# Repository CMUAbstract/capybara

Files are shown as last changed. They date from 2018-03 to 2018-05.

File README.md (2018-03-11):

# HW Design Files for Capybara board

Capybara is an energy-harvesting sensor node that runs on solar panels or RF
energy (from 915MHz RFID transmitters), and features a power system with
reconfigurable energy storage for provisioning energy bursts on demand
([details and link to
paper](https://github.com/CMUAbstract/releases/blob/master/Capybara.md)). The board
includes the following sensors:

* IMU: LSM6DS3
* Magnetometer: HMC5883L
* Proximity/Gesture/Light/Color: APDS-9960
* Barometer: LPS22HB
* Phototransistor
* Analog MEMS microphone

[Schematic PDF](Project%20Outputs%20for%20Capybara/CapybaraSchematic.PDF)

[Gerber and Drill files](Project%20Outputs%20for%20Capybara/capybara-v2-gerber)

[BOM](Project%20Outputs%20for%20Capybara/BOM-v2-0.xls)

Please contact us if you are interested in blank or assembled PCB boards.

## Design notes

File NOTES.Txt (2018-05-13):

No BQ bypass configuration:
Can use internal supervisor inside BQ (VBAT_OK) for BOOST_EN signal
populate R73
unpopulate R60

optionally for VBANK_OK signal for the MCU populate either:
   to use the supervisor as the source of the signal: populate R63 and R62,  unpopulate R61
   to use the VBAT_OK as the source of the signal: populate R61, unpopulate R63, R62.

With BQ bypass, CANNOT use the internal (VBAT_OK) for BOOST_EN signal,
because during the bypass BQ output is disconnected from the main cap,
so it will reach top voltage, and VBAT_OK will go high, BEFORE the
main cap bank charges.

Tested cap config:
Output of output booster (C51,C52,C53): none
Input of output booster (C44,C45): 100uF     (ceramic)
Bank0-internal (C30,C31,C29): 200uF=2x 100uF (ceramic)
Bank0 (C1,C2): none

Tested config:
Use U9 (BU49) supervisor for ON trigger: works  (config chosen, i.e. last tested)
Use VBAT_OK interal supervisor in BQ for ON trigger: works

Issue: zigzag in VDD -- possibly due to the failed-start problem (tune C54,R86 on gate of shutdown FET Q26).

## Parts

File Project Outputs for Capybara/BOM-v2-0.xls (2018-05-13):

Distributor | Comment | Description | Designator | Distributor Part Number | LibRef | Manufacture Part Number | Manufacturer | Manufacturer Part Number | Quantity | Value | Layer
Mouser | Cap - Polarized | Polarized Capacitor | C1, C2, C3, C4, C5, C6, C7, C8, C9, C10, C11, C12, C13, C14 | 628-CPX3225A752D | Cap - Polarized |  | Seiko Instruments | CPX3225A752D | 14 | 7.5mF | Bottom
Mouser | 304DCN2R7SCBB | EDLC Supercap | C15, C16, C17, C18, C19 | 598-304DCN2R7SCBB | SUPERCAP |  | Illinois Capacitor / CDE | 304DCN2R7SCBB | 5 | 300mF | Bottom
Mouser | SUPERCAP_DUAL_SERIES | EDLC Supercap Dual with Balancing Terminal | C20 | 81-DMT3N4R2U224M3DT0 | SUPERCAP_DUAL_SERIES |  | Murata Electronics | DMT3N4R2U224M3DTA0 | 1 | 220mF | Bottom
Mouser | SUPERCAP_DUAL | EDLC Supercap Dual | C21 | 81-DMHA14R5V353M4ATA | SUPERCAP_DUAL |  | Murata Electronics | DMHA14R5V353M4ATA0 | 1 | 35mF | Bottom
Digi-Key | Cap | Ceramic Capacitor (Surface Mount) | C22, C23, C24, C25, C59, C60, C82, C107 | 490-1543-1-ND | Cap |  | Murata Electronics North America | GRM188R61A105KA61D | 8 | 1uF | Bottom, Bottom, Bottom, Bottom, Top, Top, Top, Top
Digi-Key | Cap | Ceramic Capacitor (Surface Mount) | C26, C33, C35, C39, C43, C49, C50, C62, C64, C67, C68, C74, C75, C76, C77, C78, C102, C112, C113, C115, C117 | 490-1532-1-ND | Cap |  | Murata Electronics North America | GRM188R71C104KA01D | 21 | 0.1uF | Bottom, Bottom, Bottom, Bottom, Bottom, Bottom, Bottom, Top, Top, Top, Top, Top, Top, Top, Top, Top, Top, Bottom, Top, Bottom, Bottom
Digi-Key | Cap | Ceramic Capacitor (Surface Mount) | C27, C28, C32, C37, C42, C55, C56, C57, C58, C71, C72, C104, C118, C120, C121 | 490-3296-1-ND | Cap |  | Murata Electronics North America | GRM188R61C225KE15D | 15 | 2.2uF | Bottom, Bottom, Bottom, Bottom, Bottom, Top, Top, Top, Top, Top, Top, Top, Bottom, Bottom, Bottom
Digi-Key | Cap | Ceramic Capacitor (Surface Mount) | C29 | 490-13981-1-ND | Cap |  | Murata Electronics North America | GRM21BR60J107ME15L | 1 | 100uF | Bottom
Digi-Key | Cap | Ceramic Capacitor (Surface Mount) | C30, C31, C40, C44, C45, C51, C52, C53 | 490-10510-1-ND | Cap |  | Murata Electronics North America | GRM21BR60G107ME15L | 8 | 100uF | Bottom
Digi-Key | Cap | Ceramic Capacitor (Surface Mount), Ceramic Capacitor (Surface Mount), CAP CER 4.7UF 4V X6S, Ceramic Capacitor (Surface Mount) | C34, C63, C65, C103 | 1276-2087-1-ND | Cap |  | Samsung Electro-Mechanics | CL10B475KQ8NQNC | 4 | 4.7uF | Bottom, Top, Top, Top
Digi-Key | Cap | Ceramic Capacitor (Surface Mount) | C36, C66, C119 | 490-3290-1-ND | Cap |  | Murata Electronics North America | GRM188R71E224KA88D | 3 | 0.22uF | Bottom, Top, Bottom
Digi-Key | Cap | Ceramic Capacitor (Surface Mount) | C38 | 1276-6528-1-ND | Cap |  | Samsung Electro-Mechanics | CL10A476MR8NZNE | 1 | 47uF | Bottom
Mouser | Cap | Ceramic Capacitor (Surface Mount) | C41 | 80-C0603C103J5R | Cap |  | KEMET | C0603C103J5RACTU | 1 | 0.01uF | Bottom
Digi-Key | Cap | Ceramic Capacitor (Surface Mount) | C46, C73, C79 | 490-3896-1-ND | Cap |  | Murata Electronics North America | GRM188R60J106ME47D | 3 | 10uF | Bottom, Top, Top
Digi-Key | Cap | Ceramic Capacitor (Surface Mount) | C47 | 490-10748-1-ND | Cap |  | Murata Electronics North America | GRM21BR61E106MA73L | 1 | 10uF | Bottom
 | Cap | Ceramic Capacitor (Surface Mount) | C48 |  | Cap |  | Generic Ceramic Chip Cap (TBD) |  | 1 | TBD | Bottom
Digi-Key | Cap | Ceramic Capacitor (Surface Mount) | C54 | 1276-1984-1-ND | Cap |  | Samsung Electro-Mechanics | CL10B203KB8NNNC | 1 | 0.02uF | Bottom
Digi-Key | Cap - Polarized | Polarized Capacitor | C61 | 490-10510-1-ND | Cap - Polarized |  | Murata Electronics North America | GRM21BR60G107ME15L | 1 | 100uF | Top
Digi-Key | Cap | Ceramic Capacitor (Surface Mount) | C69, C70, C101, C105 | 399-1061-1-ND | Cap |  | Kemet | C0603C101J5GACTU | 4 | 100pF | Top
Mouser | Cap | Ceramic Capacitor (Surface Mount) | C80, C81 | 581-04025A100MAT2A | Cap |  | AvX | 04025A100MAT2A | 2 | 10pF | Top
Digi-Key | Cap | Ceramic Capacitor (Surface Mount) | C83, C84 | 490-8222-1-ND | Cap |  | Murata Electronics North America | GRM1555C1H6R0CA01D | 2 | 6pF | Top
Digi-Key | Cap | Ceramic Capacitor (Surface Mount) | C85, C114 | 490-1459-1-ND | Cap |  | Murata Electronics North America | GRM1885C1H222JA01D | 2 | 2.2nF | Top
Digi-Key | Cap | Ceramic Capacitor (Surface Mount) | C86, C87, C90, C92, C99 | 490-6073-1-ND | Cap |  | Murata Electronics | GJM1555C1H1R0BB01D | 5 | 1pF | Top
 | Cap | Ceramic Capacitor (Surface Mount) | C88, C89 |  | Cap |  | Generic Ceramic Chip Cap (TBD) |  | 2 |  | Top
Digikey | Cap | Ceramic Capacitor (Surface Mount) | C91 | 490-6263-1-nd | Cap |  | Murata Electronics |  | 1 | 0.5pF | Top
Mouser | Cap | Ceramic Capacitor (Surface Mount) | C93, C94, C97 | 609-500R07S330JV4T | Cap |  | Johanson | 500R07S330JV4T | 3 | 33pF | Top
Mouser | Cap | Ceramic Capacitor (Surface Mount) | C95 | 609-500R07S5R6CV4T | Cap |  | Johanson | 500R07S5R6CV4T | 1 | 2.2pF | Top
Digi-Key | Cap | Ceramic Capacitor (Surface Mount) | C96 | 490-1312-1-ND | Cap |  | Murata Electronics North America | GRM155R71E103KA01D | 1 | 10000pF | Top
Mouser | Cap | Ceramic Capacitor (Surface Mount) | C98 | 609-500R07S100JV4T | Cap |  | Johanson | 500R07S100JV4T | 1 | 10pF | Top
Mouser | Cap | Ceramic Capacitor (Surface Mount) | C100 | 81-GRM1555C1H102JA1D | Cap |  | Generic Ceramic Chip Cap (TBD) | GRM1555C1H102JA01D | 1 | 1000pF | Top
Digi-Key | Cap | Ceramic Capacitor (Surface Mount) | C106 | 445-5192-1-ND | Cap |  | TDK Corporation | C1608X7R1C474K080AC | 1 | 0.47uF | Top
Digi-Key | Cap | Ceramic Capacitor (Surface Mount) | C108, C109 | 490-5867-1-ND | Cap |  | Murata Electronics North America | GRM1555C1H8R0DA01D | 2 | 8pF | Top
Digi-Key | Cap | Ceramic Capacitor (Surface Mount) | C110, C111 | 490-5873-1-ND | Cap |  | Murata Electronics North America | GRM1555C1H4R0CA01D | 2 | 4pF | Top
Digi-Key | Cap | Ceramic Capacitor (Surface Mount) | C116 | 490-3287-1-ND | Cap |  | Murata Electronics North America | GRM188R71H473KA61D | 1 | 0.047uF | Bottom
Mouser | COAX_SMALL | ms-156hf | CO1 | 798-MS156HF20 | COAX_SMALL |  | Hirose Connector | MS-156HF(20) | 1 |  | Top
Mouser | Diode | General Purpose Diode | D1, D2, D3, D4, D5, D6, D7, D8, D9, D10, D11, D12, D13, D14, D15, D16, D17, D18, D19, D20, D21, D22, D23, D24, D25, D26, D27, D29, D30, D31, D32, D33, D34, D35, D36, D39, D40 | 78-BAS40-02V-V-G-08 | Diode |  | Vishay Semiconductor | BAS40-02V-V-G-08 | 37 |  | Bottom, Bottom, Bottom, Bottom, Bottom, Bottom, Bottom, Bottom, Bottom, Bottom, Bottom, Bottom, Bottom, Bottom, Bottom, Bottom, Bottom, Bottom, Bottom, Bottom, Bottom, Bottom, Bottom, Bottom, Bottom, Bottom, Bottom, Bottom, Bottom, Bottom, Bottom, Bottom, Bottom, Bottom, Top, Bottom, Bottom
Digikey | 3.0V | 1.0 A Surface Mount Schottky Barrier Rectifier, 40 V, -65 to 125 degC, 2-Pin SOD-123 Package, RoHS, Tape and Reel | D28 | MMSZ4683-TPMSCT-ND | CMP-0303-00003-1 |  | Micro Commercial Co | MMSZ4683-TP | 1 |  | Bottom
Mouser | HSMS-285C | Agilent Schottky Diode, Two in Series, Small Package SOT-323 | D37, D38 | 630-HSMS-285C-BLKG | HSMS-285C |  | Avago Technologies US Inc. | HSMS-285C-BLKG | 2 |  | Top
 | FIDUCIAL |  | F1, F2, F3 |  | FIDUCIAL |  |  |  | 3 |  | Top
Digikey | Ferrite Bead | Ferrite bead, RF choke | FB1, FB2 | 490-5216-1-ND | Ferrite Bead |  | Murata Electronics North America | BLM18HE152SN1D | 2 |  | Top
Digikey | JTAG | Header, 50mil, 5x2, Gold, TH | J1 | SAM8798-ND | GRPB052VWVN-RC |  | Samtec Inc. | FTSH-105-01-L-D-K | 1 |  | Top
Mouser | MMCX | MMCX RF Connector | J2 | 538-73415-1001 | MMCX |  | Molex | 0734151001 | 1 |  | Top
 | JUMPER |  | JU1, JU2 |  | JUMPER |  |  |  | 2 |  | Bottom
Mouser | Ind | Inductor | L1, L2 | 994-PFL1609-472MEU | Inductor |  | Coilcraft | PFL1609-472MEU | 2 | 4.7uH | Bottom
Mouser | Ind | Inductor (Surface Mount) | L3 | 963-LB1608T100M | Ind |  | Taiyo Yuden | LB1608T100M | 1 | 10uH | Top
Digikey | Ind | Inductor (Surface Mount) | L4 | 490-8389-1-ND | Ind |  | Murata Electronics North America | LQG15HS2N4S02D | 1 | 2.4nH | Top
Digikey | Ind | Inductor (Surface Mount) | L5, L6 | 490-6569-1-ND | Ind |  | Murata Electronics North America | LQG15HS2N0S02D | 2 | 2nH | Top
Digikey | Ind | Inductor (Surface Mount) | L7 | 490-8389-1-ND | Ind |  | Murata Electronics North America | Murata Electronics North America | 1 | 2.4nH | Top
Mouser | Ind | Inductor (Surface Mount) | L8 | 994-0402CS-22NXGLU | Ind |  | Coilcraft (http://www.coilcraft.com/0402cs.cfm) | 0402CS-22NX_LU | 1 | 22nH | Top
Digikey | JMPHDR_12 |  | P1 | S9015E-12-ND | JMPHDR_12 |  | Sullins Connector Solutions | GRPB122VWVN-RC | 1 |  | Top
Digikey | JMPHDR_8 |  | P2 | S9015E-08-ND | JMPHDR_8 |  | Sullins Connector Solutions | GRPB082VWVN-RC | 1 |  | Top
Mouser | MHDR1X8 | Header, 8-Pin | P3, P6, P9 | 855-M52-5000845 | MHDR1X8 |  | Harwin Inc. | M52-5000845 | 3 |  | Top
Digikey | JMPHDR_6 |  | P4 | S9015E-06-ND | JMPHDR_6 |  | Sullins Connector Solutions | GRPB062VWVN-RC | 1 |  | Top
Mouser | MHDR1X4 | Header, 4-Pin | P5, P14 | 855-M52-5000445 | MHDR1X4 |  | Harwin Inc. | M52-5000445 | 2 |  | Top
Digikey | MHDR1X6 | Header, 6-Pin | P7 | 855-M52-5000645 | MHDR1X6 |  | Harwin Inc. | M52-5000645 | 1 |  | Top
Mouser | MHDR1X7 | Header, 7-Pin | P8 | 855-M52-5000745 | MHDR1X7 |  | Harwin Inc. | M52-5000745 | 1 |  | Top
Mouser | MHDR1X3 | Header, 3-Pin | P10 | 855-M52-5000345 | MHDR1X3 |  | Harwin Inc. | M52-5000345 | 1 |  | Top
Digikey | MHDR1X2 | Header, 2-Pin | P11 | SAM9931-ND | MHDR1X2 |  | Samtec Inc. | SLM-102-01-S-S | 1 |  | Top
Mouser | Debug | Header, 4-Pin | P12 | 855-M52-5000445 | MHDR1X4 |  | Harwin Inc. | M52-5000445 | 1 |  | Top
Mouser | APP | Header, 4-Pin | P13 | 855-M52-5000445 | MHDR1X4 |  | Harwin Inc. | M52-5000445 | 1 |  | Top
Mouser | PMOS | P-Channel MOSFET | Q1, Q2, Q3, Q4, Q17, Q18, Q19, Q20, Q21, Q22, Q23, Q24, Q30 | 771-PMV30XPEAR | MOSFET-P |  | Nexperia | PMV30XPEAR | 13 | PMOS | Bottom
Mouser | NMOS | N-Channel MOSFET | Q5, Q6, Q7, Q8, Q13, Q14, Q15, Q16 | 781-SI2302CDS-E3 | MOSFET-N |  | Vishay Siliconix | SI2302CDS-T1-E3 | 8 | NMOS | Bottom
Mouser | NMOS | N-Channel MOSFET | Q9, Q10, Q11, Q12 | 621-DMN65D8L-7 | MOSFET-N |  | Diodes Incorporated | DMN65D8L-7 | 4 | NMOS | Bottom
Digi-Key | NMOS | N-Channel MOSFET | Q25, Q26, Q28 | FDY302NZCT-ND | MOSFET-N |  | Fairchild | FDY302NZ | 3 | NMOS | Bottom, Bottom, Top
Mouser | SFH3710 | NPN Phototransistor | Q27 | 720-SFH3710-3/4-Z | Photo NPN |  | OSRAM Opto Semiconductors Inc | SFH 3710-3/4-Z | 1 |  | Top
Mouser | BF2040 | N-Channel RF MOSFET 1GHz, 40mA | Q29 | 726-BF2040E6814HTSA1 | BF2040 |  | NXP Semiconductors | BF2040E6814HTSA1 | 1 |  | Top
Digikey | NMOS | N-Channel MOSFET | Q31 | SI2302CDS-T1-E3CT-ND | MOSFET-N |  | Vishay Siliconix | SI2302CDS-T1-E3 | 1 | NMOS | Bottom
Digi-Key | Res | Chip Resistor (Surface Mount) | R1, R2, R3, R4, R77, R83, R85, R97, R112, R113, R114 | 311-47KDCT-ND | Res |  | Yageo | RT0603DRD0747KL | 11 | 47k | Bottom, Bottom, Bottom, Bottom, Bottom, Bottom, Bottom, Top, Top, Top, Top
Digi-Key | Res | Chip Resistor (Surface Mount) | R5, R6, R7, R8, R52, R64, R65 | 311-1.00MHRCT-ND | Res |  | Yageo | RC0603FR-071ML | 7 | 1M | Bottom
Digi-Key | DB | Chip Resistor (Surface Mount) | R9, R10, R11, R12, R21, R22, R23, R24 | 311-0.0GRCT-ND | Res |  | Yageo | RC0603JR-070RL | 8 | 0 | Bottom
Digi-Key | Res | Chip Resistor (Surface Mount) | R13, R14, R15, R16 | 311-470KHRCT-ND | Res |  | Yageo | RC0603FR-07470KL | 4 | 470k | Bottom
Digi-Key | DA | Chip Resistor (Surface Mount) | R17, R18, R19, R20 | 311-0.0GRCT-ND | Res |  | Yageo | RC0603JR-070RL | 4 | 0 | Bottom
Digi-Key | Res | Chip Resistor (Surface Mount) | R25, R26, R27, R28, R29, R30, R31, R32, R33, R34, R35, R36, R37, R40, R41, R42, R43, R44, R46, R47, R49, R50, R54, R56, R59, R60, R61, R62, R63, R74, R75, R76, R80, R87, R88, R105 | 311-0.0GRCT-ND | Res |  | Yageo | RC0603JR-070RL | 36 | 0 | Bottom, Bottom, Bottom, Bottom, Bottom, Bottom, Bottom, Bottom, Bottom, Bottom, Bottom, Bottom, Bottom, Bottom, Top, Top, Top, Top, Top, Top, Bottom, Bottom, Bottom, Bottom, Bottom, Bottom, Bottom, Bottom, Bottom, Bottom, Bottom, Bottom, Bottom, Top, Top, Top
Digi-Key | Res | Chip Resistor (Surface Mount) | R38, R39, R92, R94, R95, R115 | 311-10.0KHRCT-ND | Res |  | Yageo | RC0603FR-0710KL | 6 | 10k | Bottom, Bottom, Top, Top, Top, Bottom
Digi-Key | DNP | Chip Resistor (Surface Mount) | R45, R73, R79 | 311-0.0GRCT-ND | Res |  | Yageo | RC0603JR-070RL | 3 | 0 | Top, Bottom, Bottom
Digi-Key | Res | Chip Resistor (Surface Mount) | R48 | 311-47GRCT-ND | Res |  | Yageo | RC0603JR-0747RL | 1 | 47 | Bottom
Digi-Key | Res | Chip Resistor (Surface Mount) | R51 |  | Res |  | Yageo |  | 1 | DNP | Bottom
Digi-Key | Res | Chip Resistor (Surface Mount) | R53, R57, R86, R89, R90, R96, R98, R108, R125, R131 | 311-10MGRCT-ND | Res |  | Yageo | RC0603JR-0710ML | 10 | 10M | Bottom, Bottom, Bottom, Top, Top, Top, Top, Bottom, Bottom, Bottom
Mouser | Res | Chip Resistor (Surface Mount) | R55 | 603-RC0603FR-071M37L | Res |  | Yageo | RC0603FR-071M37L | 1 | 1.37M | Bottom
Digi-Key | Resistor | Chip Resistor (Surface Mount) | R58, R128, R129 | 311-0.0GRCT-ND | Res |  | Yageo | RC0603JR-070RL | 3 | 0 | Bottom
Digi-Key | Res | Chip Resistor (Surface Mount) | R66, R93, R103, R124, R126 | YAG2319CT-ND | Res |  | Yageo | RT0603FRE07100KL | 5 | 100k | Bottom, Top, Top, Bottom, Bottom
Digi-Key | Res | Chip Resistor (Surface Mount) | R67 | 541-8.20MHCT-ND | Res |  | Vishay Dale | CRCW06038M20FKEA | 1 | 8.2M | Bottom
Mouser | Res | Chip Resistor (Surface Mount) | R68 | 71-CRCW0603-2.43M-E3 | Res |  | Vishay | CRCW06032M43FKEA | 1 | 2.43M | Bottom
Digi-Key | Res | Chip Resistor (Surface Mount) | R69, R116, R117, R118, R119 | 311-4.70MHRCT-ND | Res |  | Generic Chip Res (TBD) | RC0603FR-074M7L | 5 | 4.7M | Bottom
Digi-Key | Res | Chip Resistor (Surface Mount) | R70, R71 | YAG3327CT-ND | Res |  | Yageo | RC0603FR-071M6L | 2 | 1.6M | Bottom
Digi-Key | Res | Chip Resistor (Surface Mount) | R72 | 541-3.30MHCT-ND | Res |  | Vishay Dale | CRCW06033M30FKEA | 1 | 3.3M | Bottom
Digi-Key | Res | Chip Resistor (Surface Mount) | R78 | 311-820KHRCT-ND | Res |  | Yageo | RC0603FR-07820KL | 1 | 820k | Bottom
Digi-Key | Res | Chip Resistor (Surface Mount) | R81 | 311-200KHRCT-ND | Res |  | Yageo | RC0603FR-07200KL | 1 | 200k | Bottom
 | Res | Chip Resistor (Surface Mount) | R82 |  | Res |  | Generic Chip Res (TBD) |  | 1 | TBD | Bottom
Digi-Key | Res | Chip Resistor (Surface Mount) | R84 | 311-2543-1-ND | Res |  | Yageo | RT0603DRE0733KL | 1 | 33k | Bottom
Digi-Key | Res | Chip Resistor (Surface Mount) | R91 | MCT0603-22.0-CFCT-ND | Res |  | Vishay Beyschlag | MCT06030C2209FP500 | 1 | 22 | Top
Digi-Key | Res | Chip Resistor (Surface Mount) | R99 | P0.0JCT-ND | Res |  | Panasonic Electronic Components | ERJ-2GE0R00X | 1 | 0 | Top
Digi-Key | Res | Chip Resistor (Surface Mount) | R100 | P560KLCT-ND | Res |  | Panasonic | ERJ-2RKF5603X | 1 | 560k | Top
Digi-Key | Res | Chip Resistor (Surface Mount) | R101 | P22.0KLCT-ND | Res |  | Panasonic | ERJ-2RKF2202X | 1 | 22k | Top
Digi-Key | Res | Chip Resistor (Surface Mount) | R102 | P220KLCT-ND | Res |  | Panasonic | ERJ-2RKF2203X | 1 | 220k | Top
Digi-Key | Res | Chip Resistor (Surface Mount) | R104 | 541-1.5KGCT-ND | Res |  | Vishay Dale | CRCW06031K50JNEA | 1 | 1.5k | Top
Digi-Key | Res | Chip Resistor (Surface Mount) | R106 | 311-750KHRCT-ND | Res |  | Yageo | RC0603FR-07750KL | 1 | 760k | Top
Digi-Key | Res | Chip Resistor (Surface Mount) | R107 | 311-240KHRCT-ND | Res |  | Yageo | RC0603FR-07240KL | 1 | 240k | Top
Digi-Key | Res | Chip Resistor (Surface Mount) | R109 | 541-4.22MHCT-ND | Res |  | Vishay Dale | CRCW06034M22FKEA | 1 | 4.22M | Bottom
Digi-Key | Res | Chip Resistor (Surface Mount) | R110, R111 | 311-4.7KJRCT-ND | Res |  | Yageo | RC0402JR-074K7L | 2 | 4.7k | Top
Digi-Key | Res | Chip Resistor (Surface Mount) | R120, R121, R122, R123 | 541-20MAHCT-ND | Res |  | Vishay Dale | CRCW060320M0JPEAHR | 4 | 20M | Bottom
Digi-Key | Resistor | Chip Resistor (Surface Mount) | R127 | 311-330KHRCT-ND | Res |  | Yageo | RC0603FR-07330KL | 1 | 330k | Bottom
 | Res | Chip Resistor (Surface Mount) | R130 |  | Res |  | Generic Chip Res (TBD) |  | 1 | DNP | Bottom
 | TrisolX | TrisolX Solar Wings | S1, S2 |  | TrisolX_Solar_Wings |  | TrisolX | TrisolX Solar Wings | 2 |  | Top
Mouser | MSP430FR5994 | MSP430 - 48LQFP or 48QFN | U1 | 595-P430FR5994IRGZR | MSP430FR5994 48-pin |  | Texas Instruments | MSP430FR5994IRGZR | 1 |  | Top
Mouser | CC2650F128RHBR | Imported | U2 | 595-CC2650F128RHBT | CC2650F128RHBR |  | Texas Instruments | CC2650F128RHBT | 1 |  | Top
Digikey | ALD900xx |  | U3 | 1014-1281-5-ND | ALD9100xx |  | Advanced Linear Devices Inc. | ALD910021SAL | 1 |  | Bottom
Mouser | NCP301 | IC DETECTOR OPEN-DRAIN | U4 | 863-NCP301HSN30T1G | NCP301 |  | ON Semiconductor | NCP301HSN30T1G | 1 | 3.0v | Bottom
Mouser | SIP32413 |  | U5, U12, U13, U19 | 781-SIP32431DR3-GE3 | SIP32431 |  | Vishay Semiconductors | SIP32431DR3-T1GE3 | 4 |  | Bottom, Top, Top, Top
Quest Components | BU48 | IC DETECTOR OPEN-DRAIN | U6 | BU4917F-TR | BU48 |  | ROHM Semiconductor | BU4917F-TR | 1 |  | Bottom
Mouser | BQ25504 |  | U7 | 595-BQ25504RGTR | BQ25504 |  | BQ25504RGTT | Texas Instruments | 1 |  | Bottom
Quest Components | BU49 | IC DETECTOR CMOS | U8, U9 | BU4924F-TR | BU49 |  | ROHM Semiconductor | BU4924F-TR | 2 |  | Bottom
Digi-Key | TPS61200 |  | U10 | 296-27017-1-ND | TPS61200 |  | Texas Instruments | TPS61200DRCR | 1 |  | Bottom
Digi-Key | TPS22943DCKR | Low-Input Voltage 40 mA Current Limited Load Switch, 400 mOhms rDS(On), -40 to 85 degC, 5-pin SC70 (DCK), Green (RoHS & no Sb/Br) | U11 | 296-25316-1-ND | CMP-0329-00079-2 |  | Texas Instruments | TPS22943DCKR | 1 |  | Bottom
Mouser | APDS-9960 | Avago APDS-9960 digital proximity, ambient light, RGB, and gesture sensor. | U14 | 630-APDS-9960 | APDS-9960 |  | Broadcom Limited | APDS-9960 | 1 |  | Top
eBay | HMC5883L | IC COMPASS 3 AXIS I2C 16LCC SMD | U15 |  | HMC5883L |  | Honeywell | HMC5883L-TR | 1 |  | Top
Mouser | LPS22HB |  | U16 | 511-LPS22HBTR | LPS22HB |  | STMicroelectronics | LPS22HBTR | 1 |  | Top
Mouser | PCA9306 | I2C Level Shifter | U17 | 595-PCA9306DCURG4 | PCA9306 |  | Texas Instruments | PCA9306DCURG4 | 1 |  | Top
Mouser | LSM6DS3 |  | U18 | 511-LSM6DS3TR | LSM6DS3 |  | ST Microelectronics | LSM6DS3TR | 1 |  | Top
Mouser | Comparator | Comparator: On Semi 10uA Comparator | U20 | 863-NCS2200SQ2T2G | NCS2200 |  | ON Semiconductor | NCS2200SQ2T2G | 1 |  | Top
Mouser | SPU0414HR5H | Knowles Analog Top MEMS Microphone | U21 | 721-SPU0414HR5H-SB | SPU0414HR5H |  | Knowles | SPU0414HR5H-SB | 1 |  | Top
Mouser | MAX9914 | Low power opamp | U22 | 700-MAX9914EXKT | OPA333, 2333 | MAX9914EXK+T |  |  | 1 |  | Top
Mouser | TLV521 | Low power opamp | U23 | 595-TLV521DCKR | OPA333, 2333 |  | Texas Instruments | TLV521DCKR | 1 |  | Bottom
Mouser | FXL6408 |  | U24 | 512-FXL6408UMX | FXL6408 |  | ON Semiconductor / Fairchild | FXL6408UMX | 1 |  | Top
Digikey | ADS1115 |  | U25 | 296-38849-1-ND | ADS1115 |  | Texas Instruments | ADS1115IDGSR | 1 |  | Bottom
Mouser | MCP4541 |  | U26 | 579-MCP4541-104E/MS | MCP4541 |  | Microchip | MCP4541T-104E/MS | 1 |  | Bottom
Quest Components | BU49 | IC DETECTOR CMOS | U27 | BU4917F-TR | BU49 |  | ROHM Semiconductor | BU4917F-TR | 1 |  | Bottom
Mouser | REG710 |  | U28 | 595-REG710NA-2.7/250 | REG710 |  | Texas Instruments | REG710NA-2.7/250 | 1 | 2.7V | Bottom
Mouser | XTAL 4pin | Crystal - 4-Pin Surface Mount, [NoValue] | X1, Y2 | 520-ECS-240-8-36CKM | XTAL 4-pins, ABM11_CERAMIC_SMD_CRYSTALABM11 |  | ECS Inc. | ECS-240-8-36CKM-TR | 2 | 24Mhz | Top
Mouser | XTAL | Crystal - 2-Pin Surface Mount, Crystal Oscillator | X2, Y1 | 520-.327-6-34QCST | XTAL 2-pins, XTAL |  | ECS Inc. | ECS-.327-6-34QCS-TR | 2 | 32.768kHz | Top

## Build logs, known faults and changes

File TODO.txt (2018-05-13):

BQ VBAT_OK range: 2.5-2.537
R70=100k
R71=3.3M

Deep discharge:
1.6-1.75v doesn't prevent BQ from entering cold start occassionally,
but 1.8v seems reliable.

D25 (VBANK->VSTOR) seems to not make any difference.

Remove TPS22943: it burns massive amounts of current (~130mA for over 1ms),
and keeps burning more as you give more cap on the input of TPS61200.
Everything works without TPS22943.
** TODO: confirm that sensors (particularly, APDS) turn on without killing Vout and operate fine, without TPS22943.

I think TPS61200 is leaking more than the speced 0.5-2uA. Perhaps
the spec is for when the part is powered but EN=low, not for when
Vin is low (like 0.6V).

Double-start issue, i.e. stray shutdown
change R86 to 1M (still seeing very rare stray shutdown, so perhaps, change C54 to 0.01uF)

Find miniumum Cout cap for BQ25504. Datasheet says 100uF, so that is what we
use, but it is very very likely that it will work just fine with a much much
smaller cap, shrinking the cold start time (with BQ bypass enabled) by a lot.

Bank switches:
R=20M to 50M across the latch cap to compensate for leakage into the latch cap through Q4. This leakage causes the
latch cap to charge, even when we want it to stay low (i.e. switch close in NC config).
R8 (replenishment Q4 gate pullup): 1M->100k, to decrease leakage through Q4 (not confirmed that this makes a significant difference)
R4 (replenishment limiter): 47k->10k, because otherwise replenishment is too much for the leakage compensation

Q16 and R16 not needed for Design A (normally closed).

Why P11 (external harvester) male?

V3
---

quick layout fixes:
* Fiducial on bottom
* Remove two 90 degree turns in BLE RF trace
* move ARM JTAG header to the right (towards edge)
* move RF harvester layout downwards (for access to tuning L, C)

fix:
* P1L should go to VBANK instead of VCAP_IN
* zero-ohm on Vbank input to VarTh
* level-shifting FET+R on Vvarth_en to shift from divided Vbank to full Vbank

improvement:
* (potentially) p-FET between latch cap and gate to have enough time to charge the latch cap (when enabling empty banks)
* include WISP chargepump: S-8823A instead of BQ (as an option)
because BQ cold start is awefully inefficient, especially for RF harvester,
causing the coldstart mode to take 30s+ (under max power) and indefinitely
long for anything weaker.

features:
* configurable Vout (2io to analog switch connected to a resistor network?)
** remove U28 charge pump after adding runtime configurable output voltage from the output booster.
* external supervisor for deep discharge (1int pin)
* external Vbottom (i2c+1int) [seems to not have any advantage over using internal comparator]
* radio as I2C slave
* [MAJOR] free up one whole port for camera
** change EDB SW to work with 3 pins
** move analog inputs to former EDB aux pins
** add GPIO expander for power system

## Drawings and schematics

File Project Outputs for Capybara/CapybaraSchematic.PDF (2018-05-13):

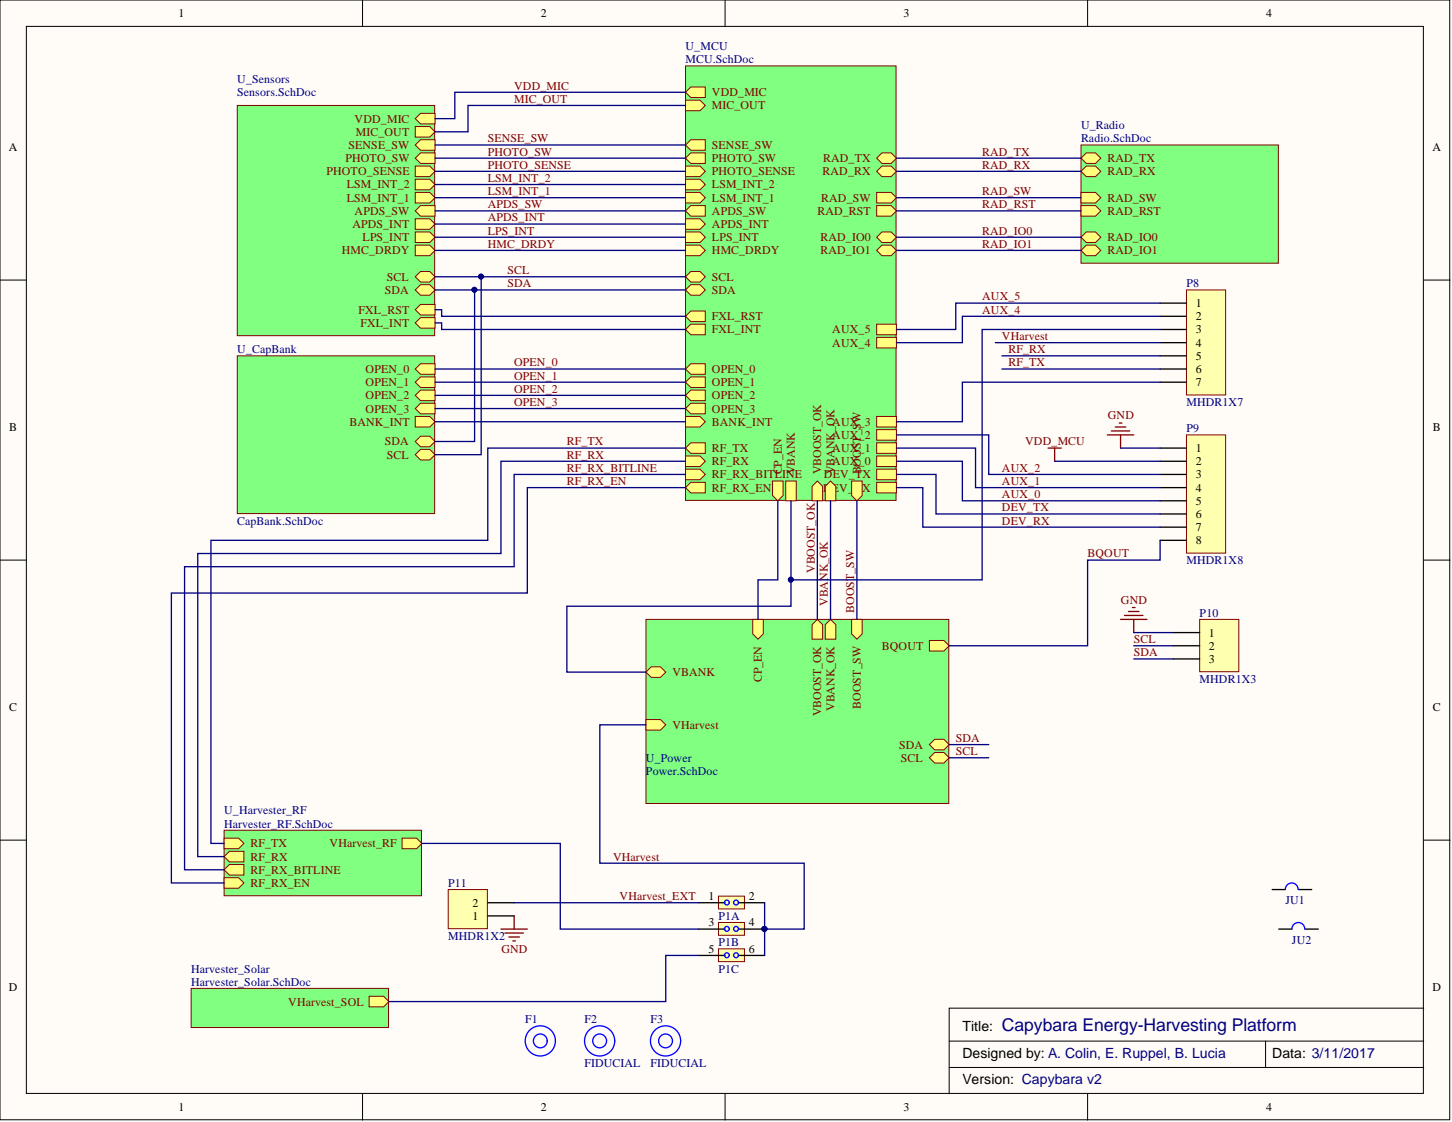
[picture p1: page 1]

PHOTO_SENSE | RAD_RX
LSM_INT_2 | RAD_SW

APDS_SW | RAD_RST
APDS_INT | RAD_IO0

OPEN_1

AUX_0
DEV_TX
DEV_RX

Title: Capybara Energy-Harvesting Platform

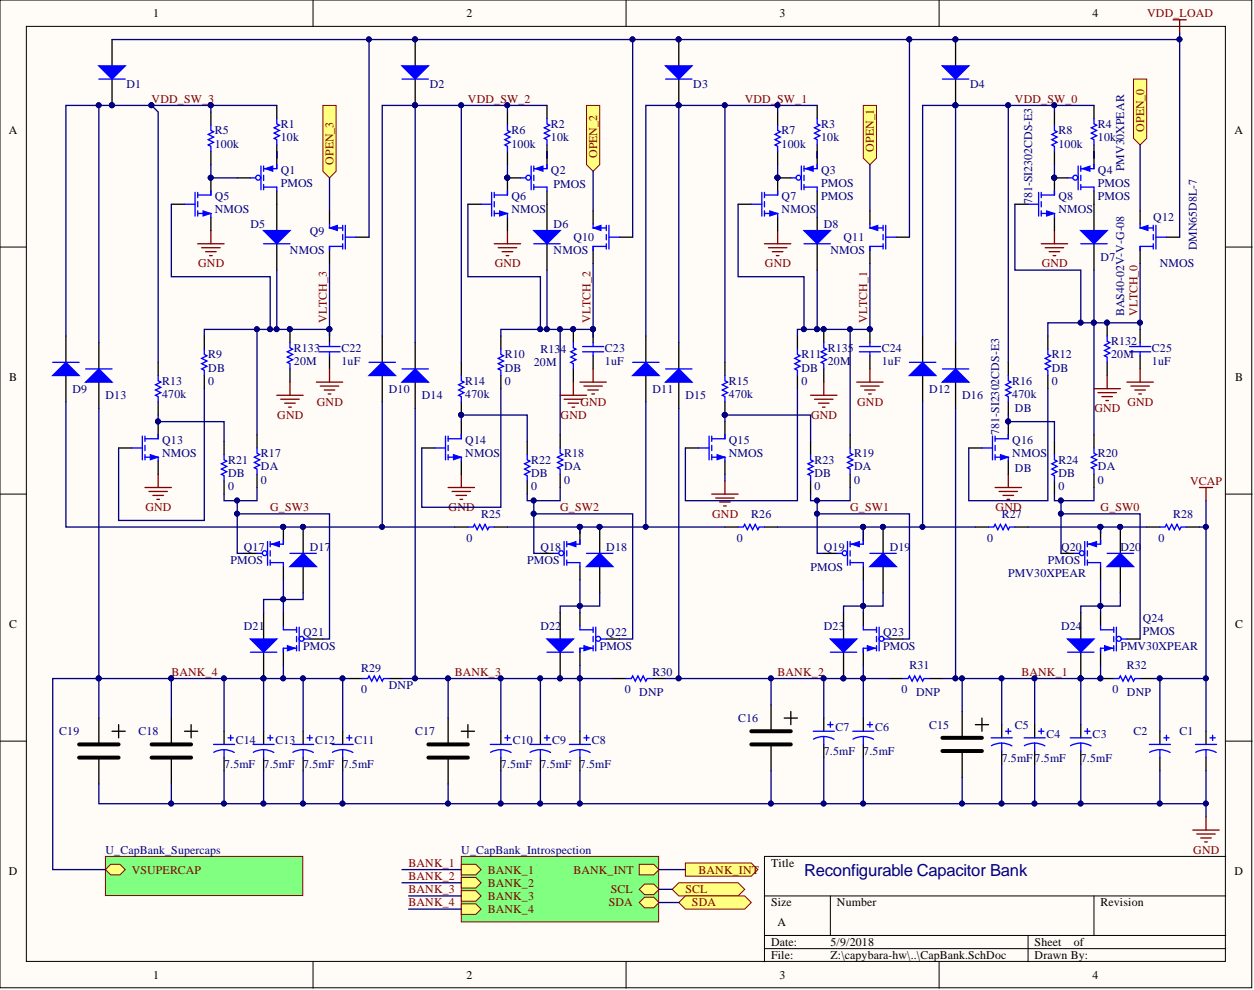
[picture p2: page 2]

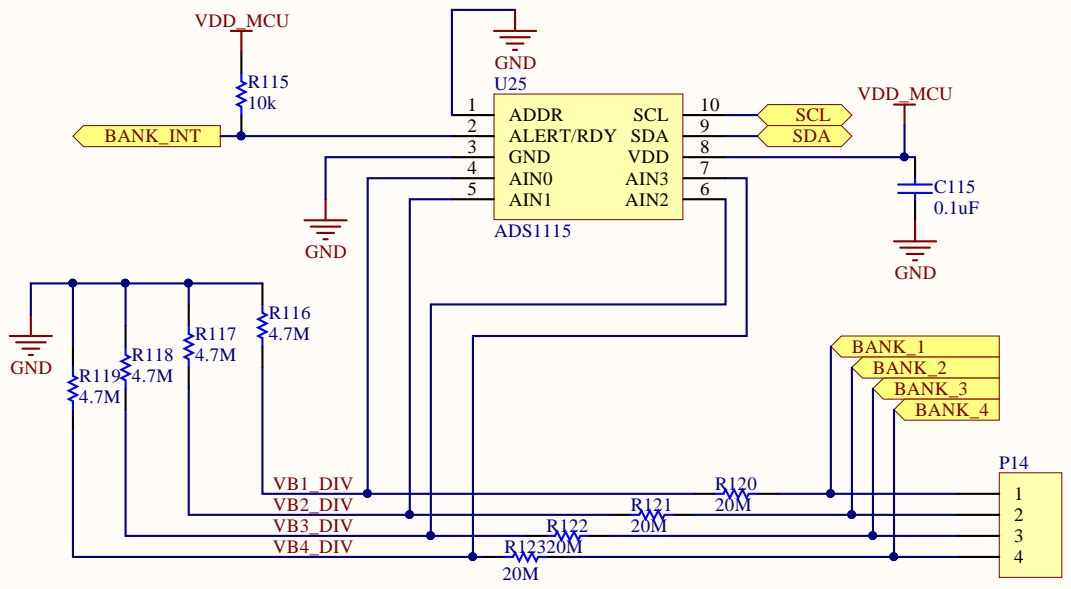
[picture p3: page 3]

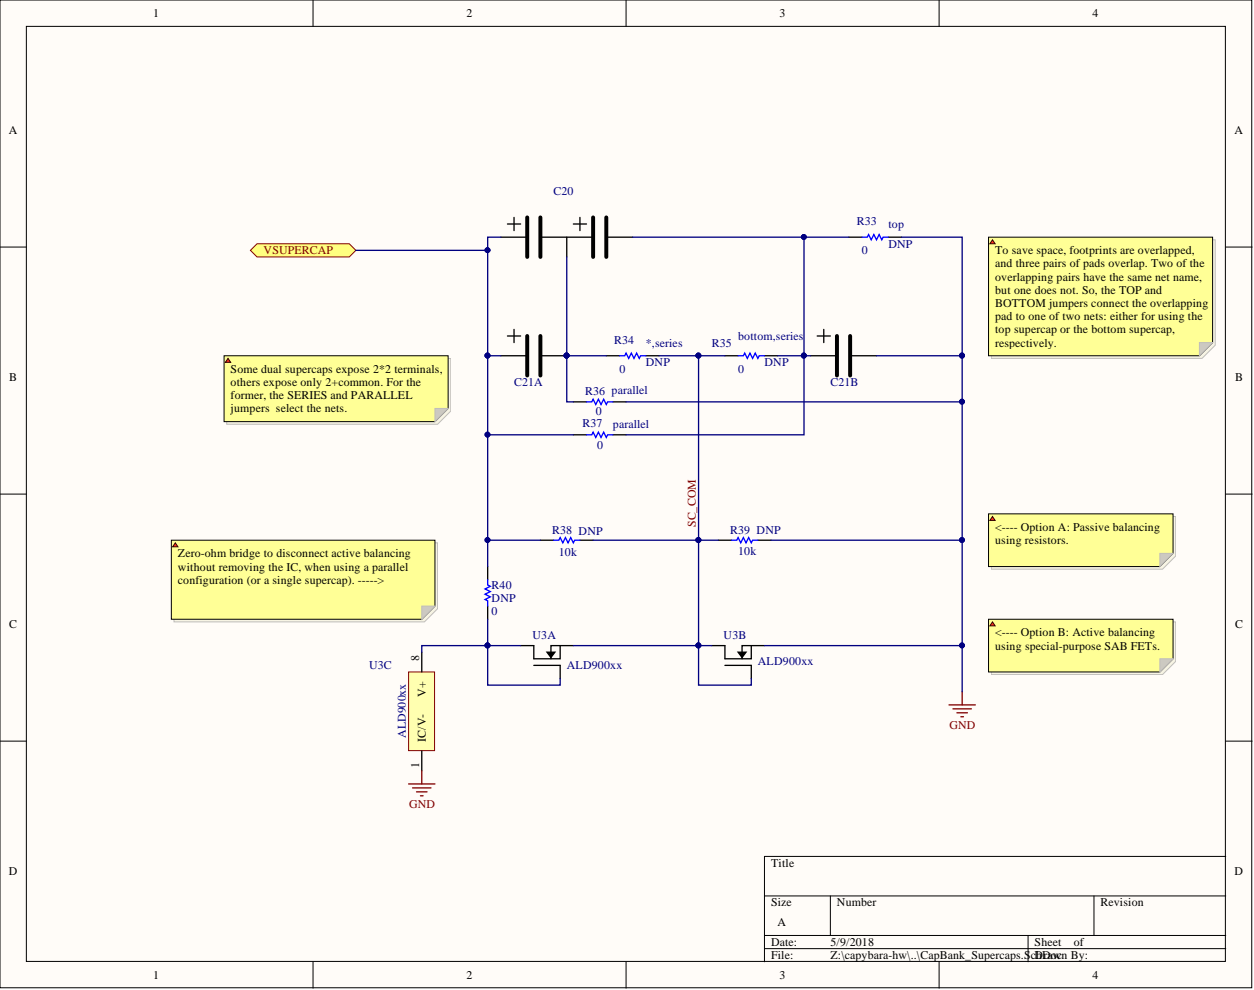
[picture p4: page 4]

To save space, footprints are overlapped,
and three pairs of pads overlap. Two of the
overlapping pairs have the same net name,
but one does not. So, the TOP and
BOTTOM jumpers connect the overlapping
pad to one of two nets: either for using the
top supercap or the bottom supercap,
respectively.

Some dual supercaps expose 2*2 terminals,
others expose only 2+common. For the
former, the SERIES and PARALLEL
jumpers select the nets.

Zero-ohm bridge to disconnect active balancing
without removing the IC, when using a parallel
configuration (or a single supercap). ----->

<---- Option B: Active balancing
using special-purpose SAB FETs.

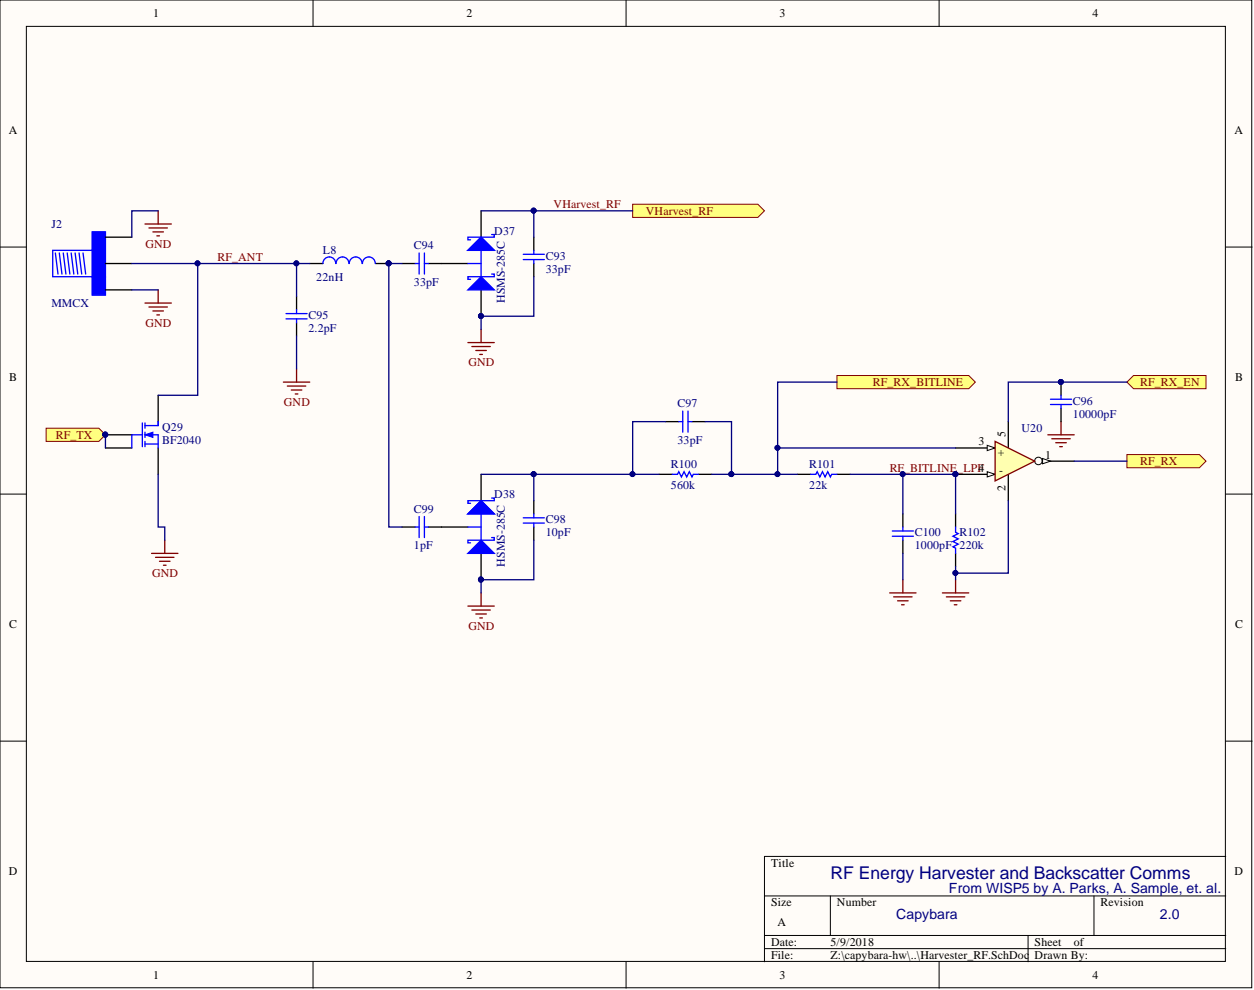
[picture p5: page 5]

RF Energy Harvester and Backscatter Com

P5 by A. Parks, A. Sample, et. al.

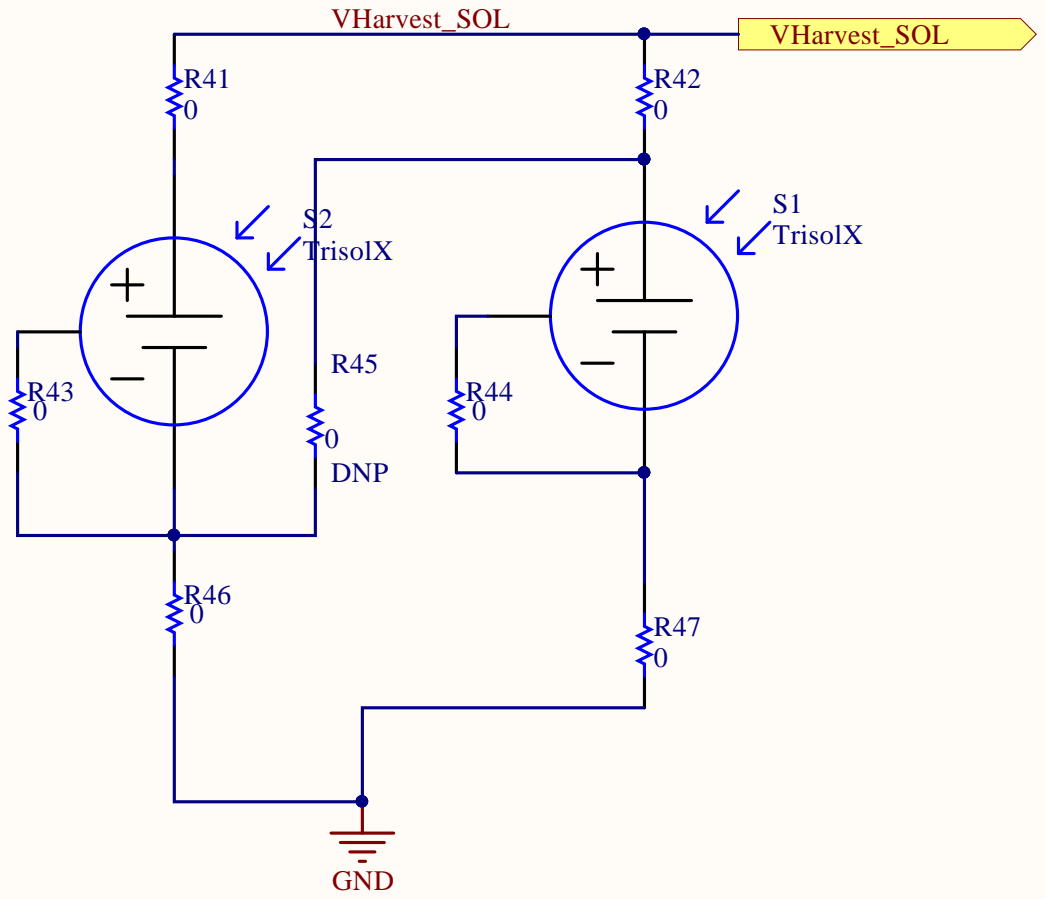
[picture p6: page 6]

Solar Panel Energy Harvester
A. Colin , E. Ruppel, B. Lucia

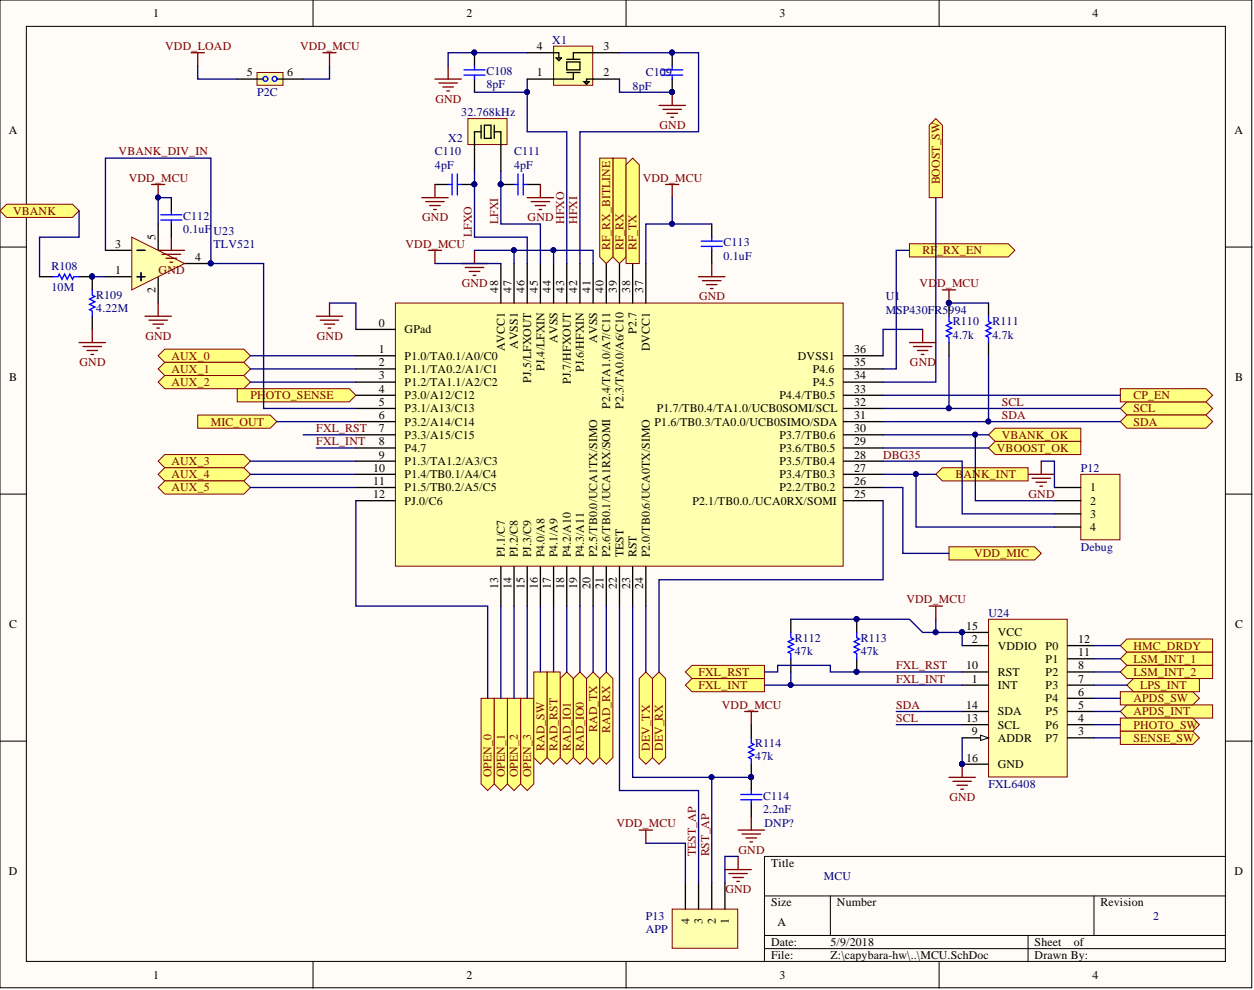
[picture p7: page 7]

AVSS 44 PJ.4/LFXIN 45 PJ.5/LFXOUT 46 AVSS1 47 AVCC1 48

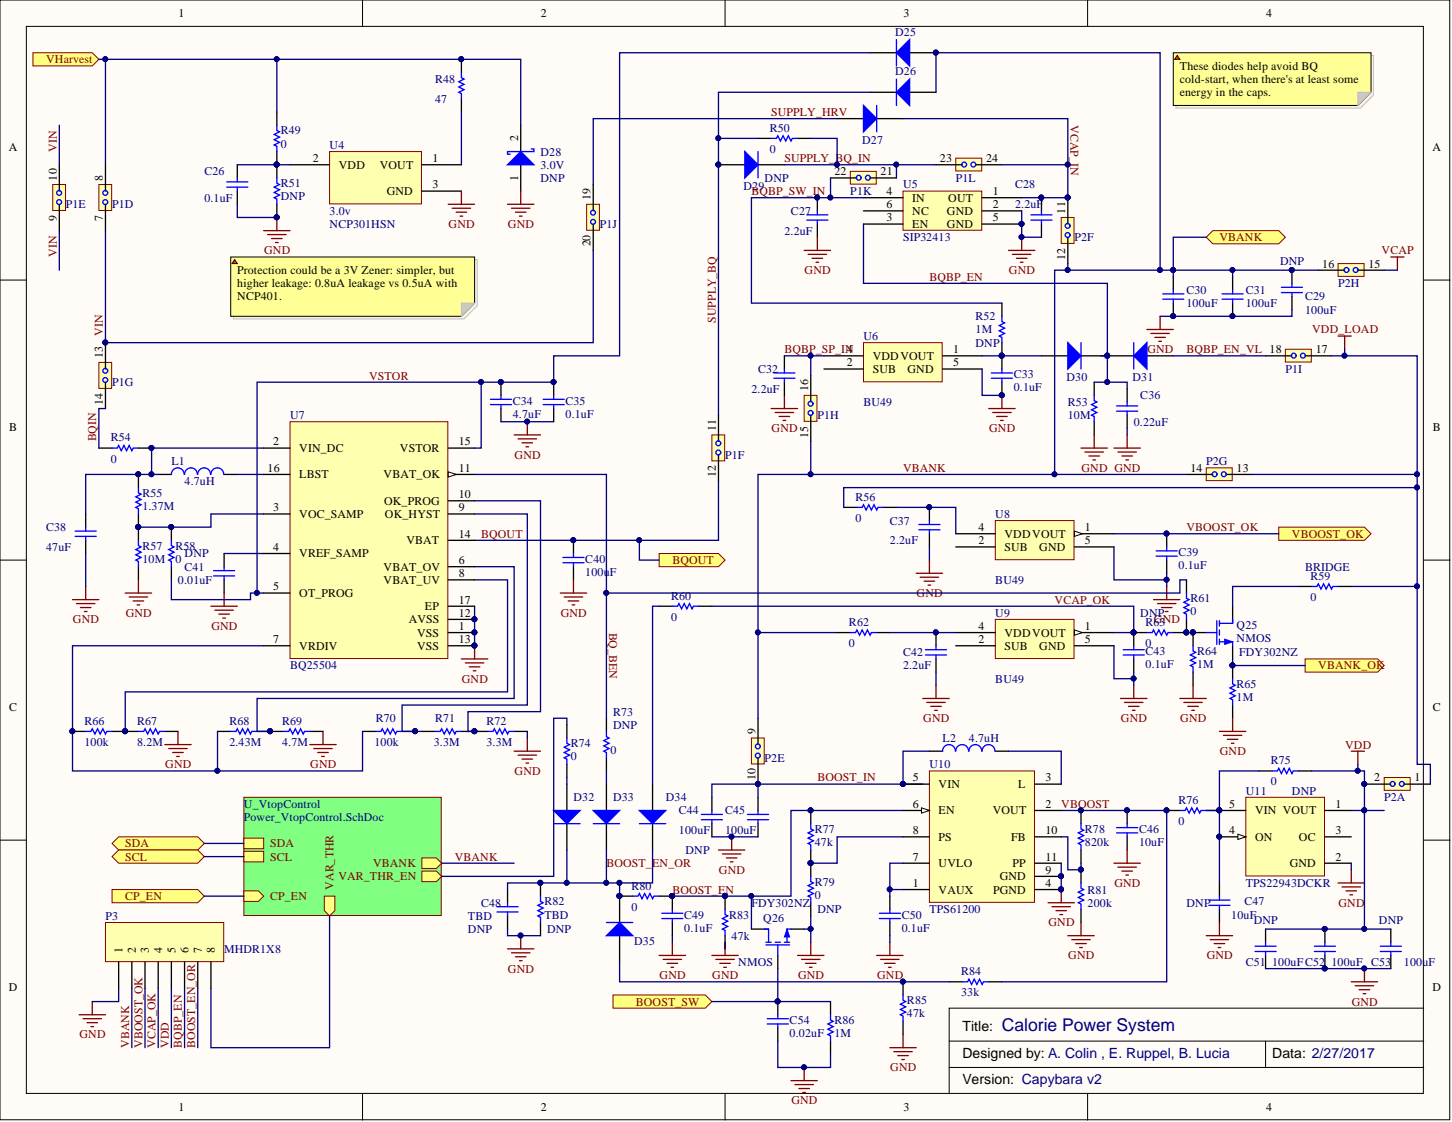
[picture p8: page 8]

These diodes help avoid BQ
cold-start, when there's at least some
energy in the caps.

SUPPLY_HRV
R50 | U5

BQBP_SW_IN | P1K

IN 4
NC 6 | GND | 2 2.2uF

GND
Protection could be a 3V Zener: simpler, but
higher leakage: 0.8uA leakage vs 0.5uA with
NCP401.

EN 6 VOUT PP GND | 2

R77 | PS 8
47k | | UVLO 7 | 11

BOOST_EN_OR

VAUX 1 | 9

Title: Calorie Power System

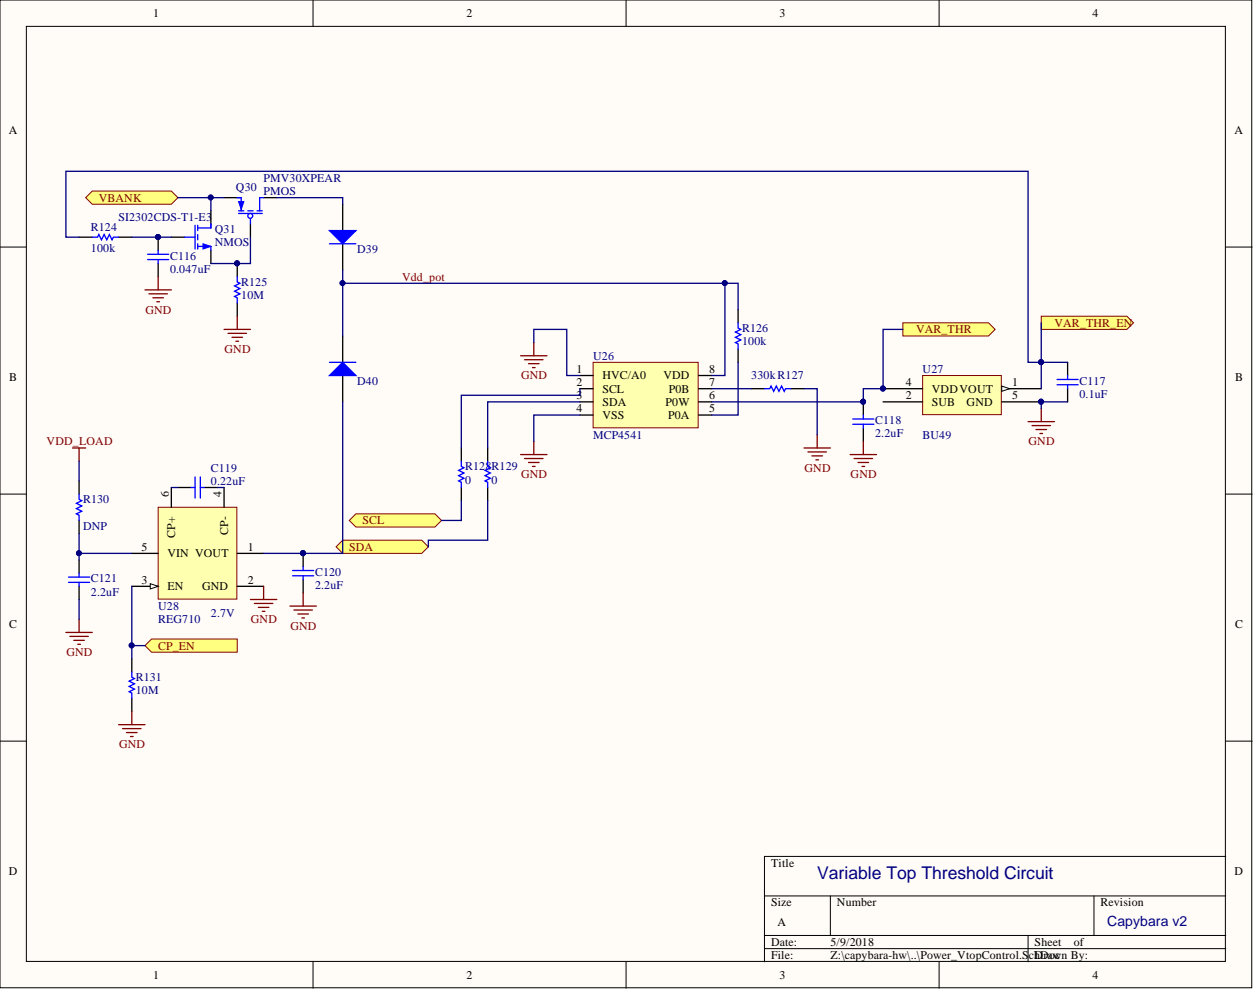
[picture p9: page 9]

Variable Top Threshold Circuit

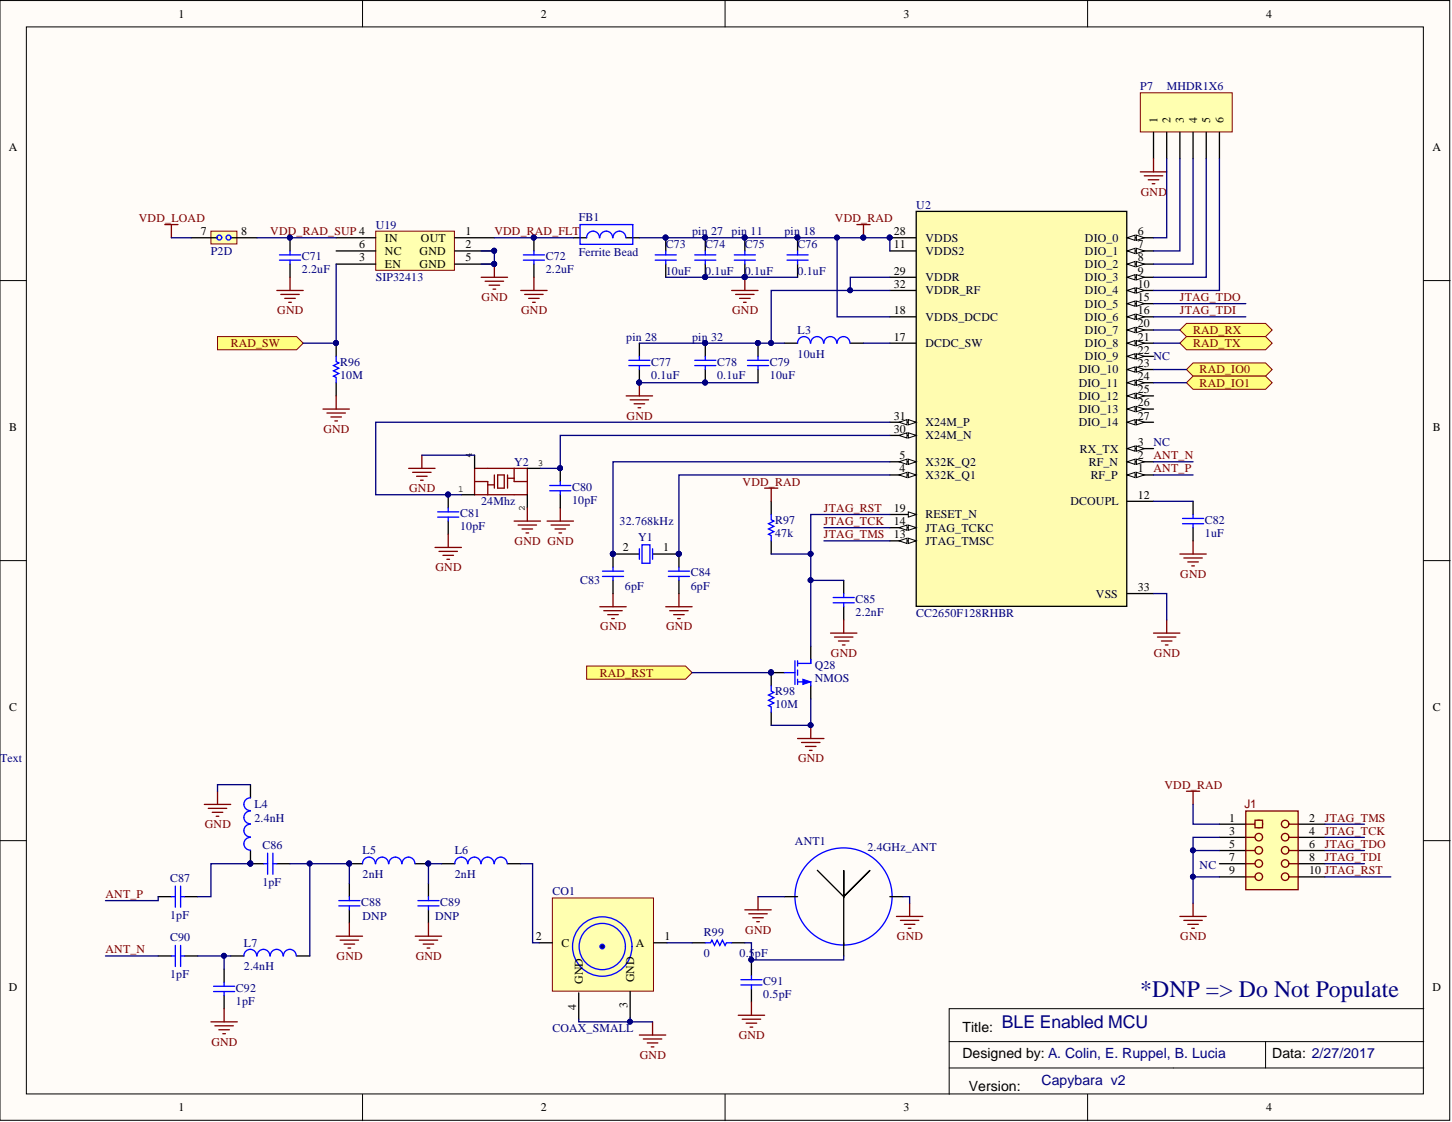
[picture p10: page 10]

C73 | | VDDS2 11

EN 3 | VDDR 29

32.768kHz | JTAG_RST

JTAG_TCK JTAG_TMS | JTAG_TMSC 13 JTAG_TCKC 14

*DNP => Do Not Populate

Title: BLE Enabled MCU

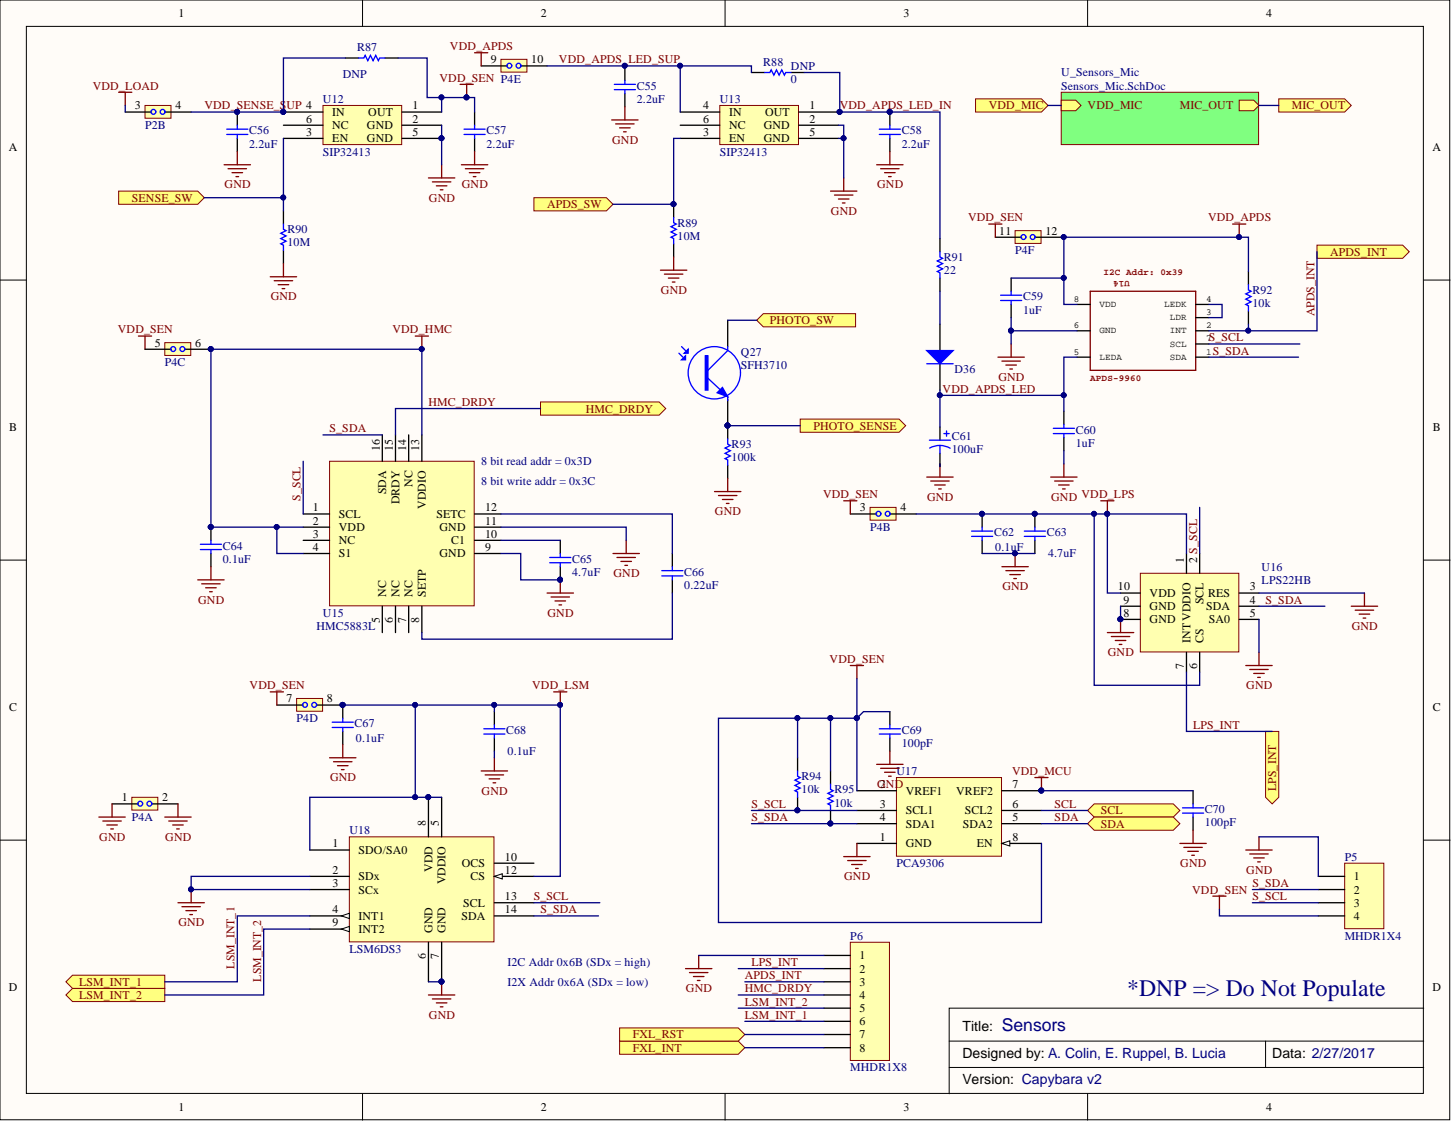
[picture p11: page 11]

*DNP => Do Not Populate

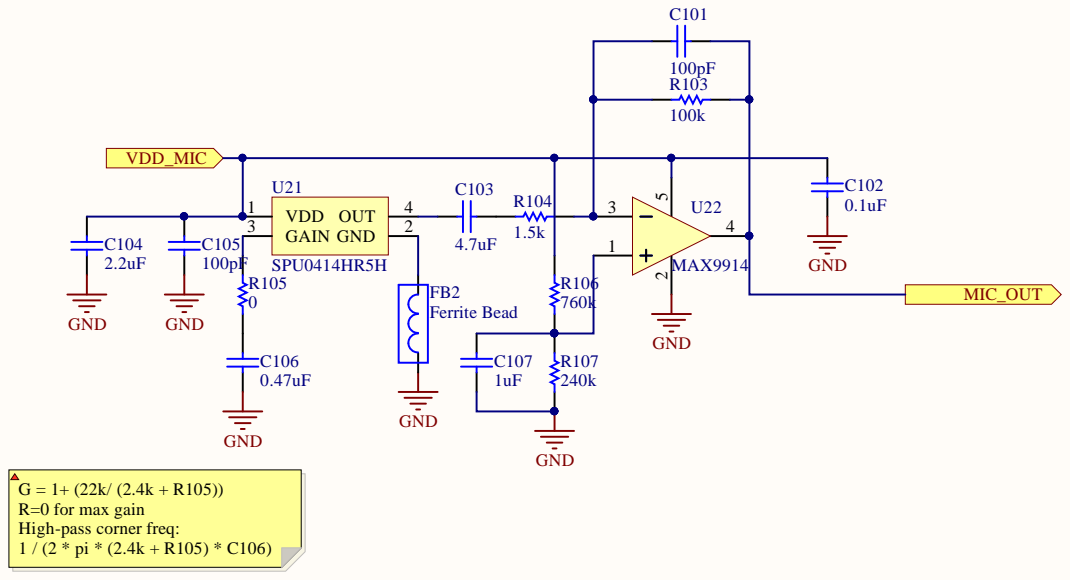
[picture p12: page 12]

R=0 for max gain
High-pass corner freq:

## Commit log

2018-03-11 HW design files for Capybara v2.0 board
    [BOM-v2-0.xls, CapBank.SchDoc, CapBank_Introspection.SchDoc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]
2018-03-11 readme: fix link to gerber
2018-03-11 readme: link to BOM
2018-03-12 BOM-v2-0.xls: updated BOM to fix old 0402 parts and separate Q5-Q16 by part number
    [BOM-v2-0.xls]
2018-05-13 sch: tuned some values, added a pulldown on Clatch
    Documented in NOTES and TODO.
    [CapBank.SchDoc, CapBank_Introspection.SchDoc, Capybara.PcbDoc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]
2018-05-13 todo: move charge pump item into V3 list
